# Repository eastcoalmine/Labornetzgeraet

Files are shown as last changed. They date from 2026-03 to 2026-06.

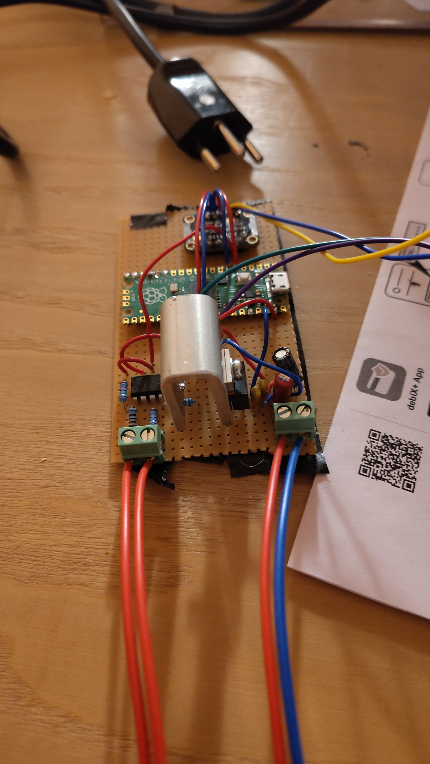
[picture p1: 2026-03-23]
Bilder/IMG_20260316_201144.jpg

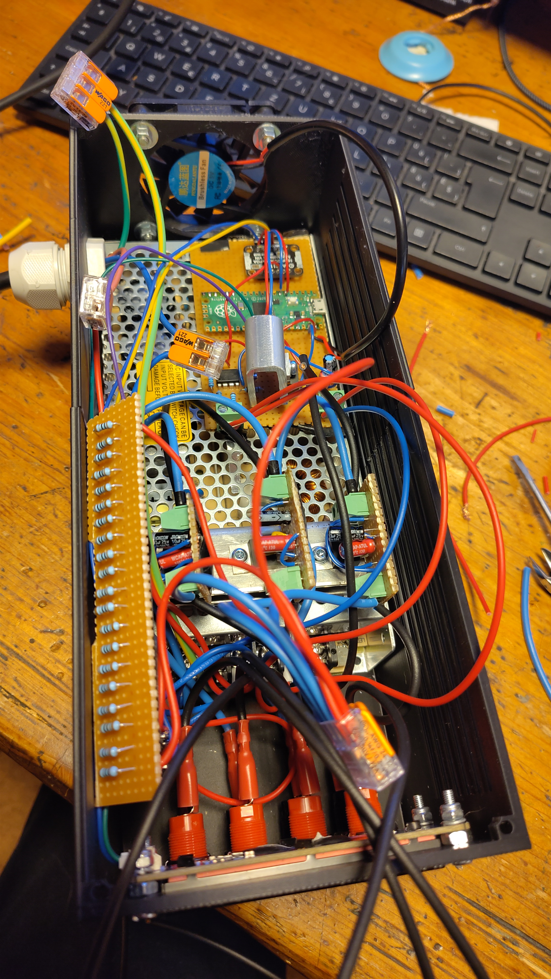
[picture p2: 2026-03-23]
Bilder/IMG_20260317_181905.jpg

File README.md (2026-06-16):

# Netzgerät

Ein Netzgerät welches 15V liefert, mit 3.3V, 5V, 12V und 15V Ausgängen versehen.

Sowie einen Shunt Widerstand welcher den Gesamtstromverbrauch misst und auf ein Display überträgt.

Logik mit Strommessung über Shunt Widerstand & Display. Wird von einem Raspberry Pi Pico (C/C++ SDK) gesteuert. Zusätzlich noch 5V Lüfter als kühlung.
Logik und Lüfter verbraucht 0.25 A bei 5V im Ruhezustand.



---

## Material

Foglendes Material wurde verbaut:

- Raspberry Pi Pico
- ADC (ADS1115)
- Display (Waveshare 1602 I2C)
- Lüfter
- Netzgerät (15V / 10 A)
- Lineare Spannungsregler (LM2937, LM7805, MC7812)
- Operationsverstärker (MCP601)
- Widerstände
- Kondensatoren

---

## Shunt Widerstand

Dieser ist auf dem GND Pfad montiert (über alle Spannungsausgänge), da bei der Montage beim VCC der Vin+ und Vin- Pin beim op amp höher sind als VCC. 

---

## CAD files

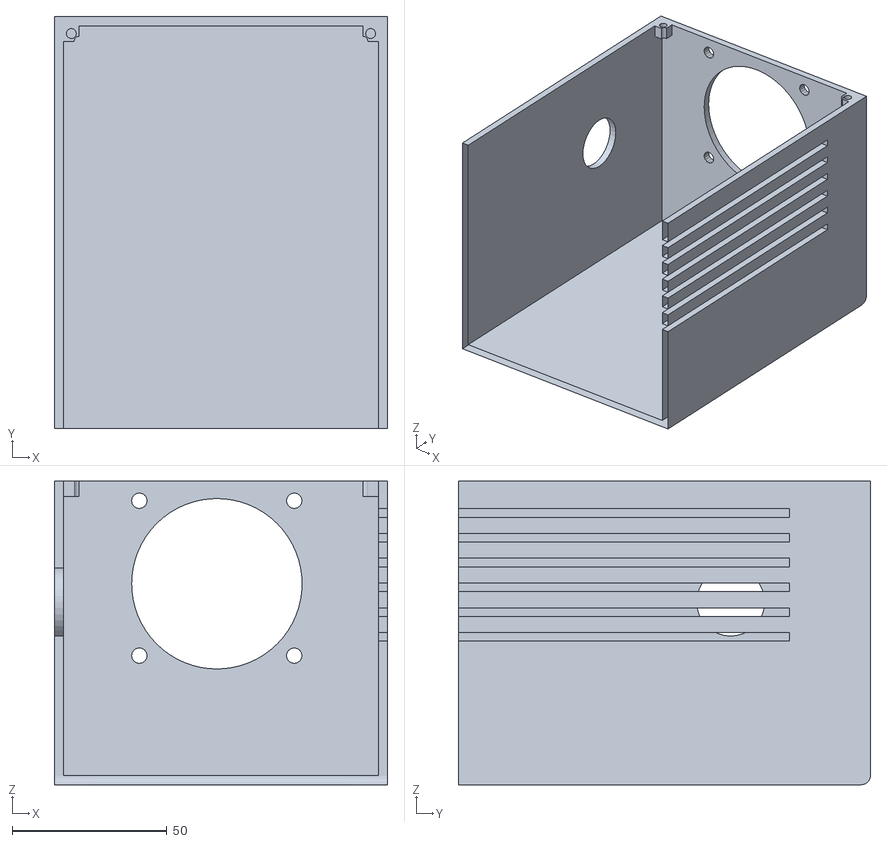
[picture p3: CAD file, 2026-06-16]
3D_Prints/body_power_3.stl
107.6 x 133.0 x 98.0

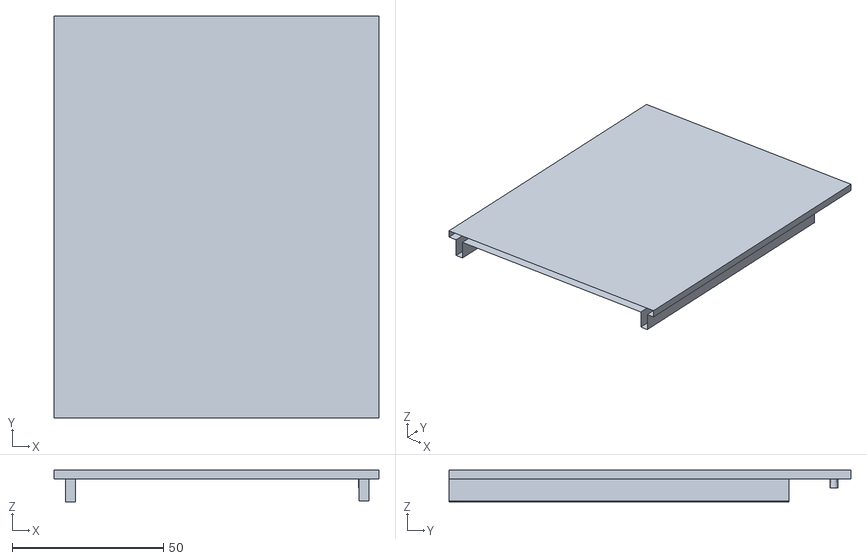
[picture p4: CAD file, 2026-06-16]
3D_Prints/top_power_2_v2.stl
107.6 x 133.0 x 10.5

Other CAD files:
3D_Prints/Labornetzgerät.3dm

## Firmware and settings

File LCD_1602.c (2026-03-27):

#include <stdio.h>
#include "pico/stdlib.h"
#include "hardware/i2c.h"
#include <hardware/adc.h>
#include "lcd1602_RGB_Module.h"

// I2C defines
#define I2C_PORT i2c0
#define I2C_SDA 6
#define I2C_SCL 7

// Taster-Pin definieren
#define CALIBRATION_BUTTON 2

// FESTE GAIN-EINSTELLUNG: ±1.024V
#define ADS_GAIN_CONFIG 0x0600
#define ADS_RANGE_V 1.024f

// GLEITENDER MITTELWERT
#define AVG_BUFFER_SIZE 10

// LINEARE REGRESSION PARAMETER (Spannungskorrektur)
#define REGRESSION_SLOPE 1.97f
#define REGRESSION_INTERCEPT 31.42f

// MA UMRECHNUNGSPARAMETER (mV zu mA - NEU KALIBRIERT)
#define MA_SLOPE 1.1165f
#define MA_INTERCEPT -36.74f

// Update-Rate für Display (in ms)
#define DISPLAY_UPDATE_MS 200

// Temperatur-Mittelwert (für stabilere Anzeige)
#define TEMP_AVG_SIZE 5

// Manueller Offset (wird bei Kalibrierung aktualisiert)
float manual_offset_mV = 0.0f;

// Ringpuffer für gleitenden Mittelwert (Strom)
float avg_buffer[AVG_BUFFER_SIZE];
int avg_index = 0;
int avg_count = 0;

// Ringpuffer für Temperatur
float temp_buffer[TEMP_AVG_SIZE];
int temp_idx = 0;
int temp_count = 0;

// ADS1115 gefunden-Status (wird einmal beim Start gesetzt)
static bool ads1115_found = false;

// Hilfsfunktion: ADS1115 konfigurieren und messen
int read_ads1115_ain0(int16_t *raw_value) {
    uint8_t config[3];
    config[0] = 0x01;
    config[1] = 0x83 | ((ADS_GAIN_CONFIG >> 8) & 0x0F);
    config[2] = 0x83 | (ADS_GAIN_CONFIG & 0xFF);

    int config_ret = i2c_write_blocking(I2C_PORT, 0x48, config, 3, false);
    if (config_ret != 3) {
        return -1;
    }

    sleep_ms(10);

    uint8_t reg = 0x00;
    i2c_write_blocking(I2C_PORT, 0x48, &reg, 1, true);
    uint8_t buf[2];
    int ret = i2c_read_blocking(I2C_PORT, 0x48, buf, 2, false);
    
    if (ret == 2) {
        *raw_value = (int16_t)((buf[0] << 8) | buf[1]);
        return 0;
    } else {
        return -1;
    }
}

// Hilfsfunktion: Rohspannung in mV berechnen
static float calculate_raw_voltage_mV(int16_t raw) {
    return (raw * ADS_RANGE_V / 32768.0f) * 1000.0f;
}

// Hilfsfunktion: Lineare Regression anwenden (Spannungskorrektur)
static float apply_linear_regression(float measured_mV) {
    return (measured_mV * REGRESSION_SLOPE) + REGRESSION_INTERCEPT;
}

// Hilfsfunktion: Korrigierte Spannung berechnen
static float calculate_corrected_voltage_mV(int16_t raw) {
    float raw_mV = calculate_raw_voltage_mV(raw);
    float offset_corrected = raw_mV - manual_offset_mV;
    return apply_linear_regression(offset_corrected);
}

// Hilfsfunktion: mV in mA umrechnen (mit Begrenzung bei 0)
static float convert_mV_to_mA(float voltage_mV) {
    float result = (voltage_mV * MA_SLOPE) + MA_INTERCEPT;
    return (result < 0.0f) ? 0.0f : result;
}

// Hilfsfunktion: Pico-Temperatur lesen (interner Sensor)
float read_pico_temperature(void) {
    // ADC für Temperatursensor aktivieren
    adc_select_input(4);
    uint16_t raw = adc_read();
    
    // Spannung berechnen (3.3V Referenz)
    float voltage = raw * 3.3f / 4095.0f;
    
    // Temperatur berechnen (Formel von Raspberry Pi)
    // 27°C bei 0.706V, -1.72mV/°C
    float temperature = 27.0f - (voltage - 0.706f) / 0.00172f;
    
    return temperature;
}

// Hilfsfunktion: Temperatur-Mittelwert aktualisieren
static float update_temp_average(float new_temp) {
    temp_buffer[temp_idx] = new_temp;
    temp_idx = (temp_idx + 1) % TEMP_AVG_SIZE;
    
    if (temp_count < TEMP_AVG_SIZE) {
        temp_count++;
    }
    
    float sum = 0.0f;
    for (int i = 0; i < temp_count; i++) {
        sum += temp_buffer[i];
    }
    
    return sum / temp_count;
}

// Hilfsfunktion: Strom-Mittelwert aktualisieren
static float update_current_average(float new_current) {
    avg_buffer[avg_index] = new_current;
    avg_index = (avg_index + 1) % AVG_BUFFER_SIZE;
    
    if (avg_count < AVG_BUFFER_SIZE) {
        avg_count++;
    }
    
    float sum = 0.0f;
    for (int i = 0; i < avg_count; i++) {
        sum += avg_buffer[i];
    }
    
    return sum / avg_count;
}

// Hilfsfunktion: Puffer zurücksetzen
static void reset_buffers(void) {
    for (int i = 0; i < AVG_BUFFER_SIZE; i++) {
        avg_buffer[i] = 0.0f;
    }
    avg_index = 0;
    avg_count = 0;
    
    for (int i = 0; i < TEMP_AVG_SIZE; i++) {
        temp_buffer[i] = 0.0f;
    }
    temp_idx = 0;
    temp_count = 0;
}

// Hilfsfunktion: Taster entprellen
static bool button_pressed_with_debounce(void) {
    static uint32_t last_press_time = 0;
    
    bool current_state = gpio_get(CALIBRATION_BUTTON);
    uint32_t now = to_ms_since_boot(get_absolute_time());
    
    if (current_state == 0 && (now - last_press_time) > 50) {
        last_press_time = now;
        return true;
    }
    
    return false;
}

// Hilfsfunktion: Kalibrierung durchführen
void calibrate_zero_point(void) {
    int16_t raw;
    if (read_ads1115_ain0(&raw) == 0) {
        float measured_raw_mV = calculate_raw_voltage_mV(raw);
        manual_offset_mV = measured_raw_mV;
        
        reset_buffers();
        
        clear();
        setCursor(0, 0);
        send_string("Offset gespeichert");
        
        char line2[17];
        snprintf(line2, sizeof(line2), "Offset: %.2f mV", manual_offset_mV);
        setCursor(0, 1);
        send_string(line2);
        
        sleep_ms(1500);
    } else {
        clear();
        setCursor(0, 0);
        send_string("Kalibrierung");
        setCursor(0, 1);
        send_string("FEHLGESCHLAGEN");
        sleep_ms(1500);
    }
}

// Hilfsfunktion: I2C-Scan (nur einmal beim Start)
void scan_i2c_bus(void) {
    printf("Scanning I2C bus...\n");
    bool foundAny = false;
    for (int addr = 0x03; addr <= 0x77; addr++) {
        int ret = i2c_write_blocking(I2C_PORT, addr, NULL, 0, false);
        if (ret == PICO_ERROR_GENERIC || ret < 0) continue;
        printf("  found device at 0x%02X\n", addr);
        foundAny = true;
        if (addr == 0x48) {
            ads1115_found = true;
        }
    }
    if (!foundAny) {
        printf("  no devices found on I2C bus\n");
    }
}

int main()
{
    stdio_init_all();

    printf("Pico serial debugger started at 115200 baud\n");

    // ADC initialisieren (für Temperatursensor)
    adc_init();
    adc_set_temp_sensor_enabled(true);
    printf("ADC initialized with temperature sensor enabled\n");

    // I2C initialisieren
    i2c_init(I2C_PORT, 400*1000);
    gpio_set_function(I2C_SDA, GPIO_FUNC_I2C);
    gpio_set_function(I2C_SCL, GPIO_FUNC_I2C);
    gpio_pull_up(I2C_SDA);
    gpio_pull_up(I2C_SCL);

    printf("I2C initialized on pins %d (SDA) und %d (SCL)\n", I2C_SDA, I2C_SCL);

    // I2C-Scan (nur einmal!)
    scan_i2c_bus();

    // LCD initialisieren
    LCD1602RGB_init(16, 2);
    printf("LCD initialized\n");

    // I2C-Kommunikation testen
    uint8_t test_data = 0x00;
    int ret = i2c_write_blocking(I2C_PORT, 0x3e, &test_data, 1, false);
    if (ret == 1) {
        printf("I2C LCD communication OK\n");
    } else {
        printf("I2C LCD communication failed: %d\n", ret);
    }

    ret = i2c_write_blocking(I2C_PORT, 0x60, &test_data, 1, false);
    if (ret == 1) {
        printf("I2C RGB communication OK\n");
    } else {
        printf("I2C RGB communication failed: %d\n", ret);
    }

    setRGB(30, 30, 30);
    printf("RGB set to dim white for better contrast\n");

    // Initialanzeige
    clear();
    setCursor(0, 0);
    send_string("System startet...");
    setCursor(0, 1);
    send_string(ads1115_found ? "ADS1115 OK" : "Kein ADS1115");
    sleep_ms(1500);

    // Taster initialisieren
    gpio_init(CALIBRATION_BUTTON);
    gpio_set_dir(CALIBRATION_BUTTON, GPIO_IN);
    gpio_pull_up(CALIBRATION_BUTTON);
    printf("Kalibrierungstaster initialisiert (GPIO %d)\n", CALIBRATION_BUTTON);

    // Kalibrierung beim Start durchführen
    sleep_ms(500);
    if (ads1115_found) {
        printf("Starte initiale Kalibrierung...\n");
        calibrate_zero_point();
    }

    printf("Starte Messung...\n");

    // Hauptloop
    while (1) {
        // Temperatur messen
        float raw_temp = read_pico_temperature();
        float smoothed_temp = update_temp_average(raw_temp);
        
        int16_t raw;
        
        if (ads1115_found && read_ads1115_ain0(&raw) == 0) {
            // Strom-Messung durchführen
            float raw_voltage_mV = calculate_raw_voltage_mV(raw);
            float corrected_voltage_mV = calculate_corrected_voltage_mV(raw);
            float smoothed_voltage_mV = update_current_average(corrected_voltage_mV);
            float current_mA = convert_mV_to_mA(smoothed_voltage_mV);
            
            // Kalibrierung prüfen
            if (button_pressed_with_debounce()) {
                calibrate_zero_point();
            }
            
            // Display aktualisieren (Temperatur oben, Strom unten)
            char line1[17];
            char line2[17];
            snprintf(line1, sizeof(line1), "Temp: %.1f C", smoothed_temp);
            snprintf(line2, sizeof(line2), "Strom: %.2f mA", current_mA);

            clear();
            setCursor(0, 0);
            send_string(line1);
            setCursor(0, 1);
            send_string(line2);
        } else {
            // Fehleranzeige
            char line1[17];
            char line2[17];
            snprintf(line1, sizeof(line1), "Temp: %.1f C", smoothed_temp);
            snprintf(line2, sizeof(line2), "Kein ADS1115");

            clear();
            setCursor(0, 0);
            send_string(line1);
            setCursor(0, 1);
            send_string(line2);
        }

        sleep_ms(DISPLAY_UPDATE_MS);
    }
}

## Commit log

2026-03-14 Initial commit: LCD1602 RGB with ADS1115 ADC project
2026-03-17 Update README with additional device details
    Add information about logic with fan display and Pico.
2026-03-18 Update README to include 15V output specification
2026-03-27 LCD-1602 Stromzähler mit Temperaturanzeige - finale Kalibrierung
